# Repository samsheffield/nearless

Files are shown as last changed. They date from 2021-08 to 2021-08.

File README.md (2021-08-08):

# Nearless (Nearness 1U Rework)

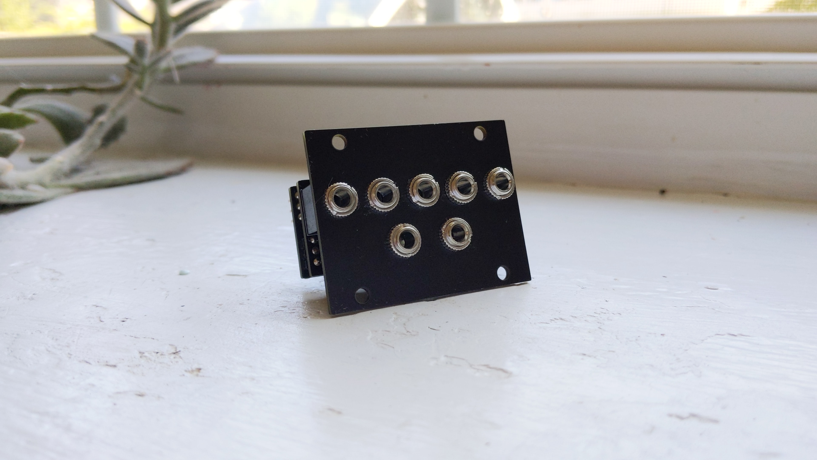
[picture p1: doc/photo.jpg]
Nearless


This is a small Intellijel 1U rework of Nearness designed by [*Jesper Särnesjö*](https://github.com/sarnesjo/nearness).

Minimal panning mixer for the Eurorack modular synthesizer system. Five inputs, two outputs. The closer an input is to either side, the greater its panning in that direction. 10hp.

Nearness is a product of the [*llllllll*](https://llllllll.co/t/prototyping-nearness-a-minimal-panning-mixer-module/8330) community.

## CHANGES

The module has been redesigned to fit an Intellijel 1U in 10hp, so there are two fewer inputs. Why 10hp? That's all I had free! :)

The resistor values have been simplified to accomodate the simple stereo spread. I tried to leave everything else as I found it.

## PCBS AND PANEL

The [kicad](kicad) directory contains the schematic and PCB and panel layouts as KiCad 5 projects.

Gerber files for fabrication are available in the [gerbers](gerbers) directory. 

Here is the [BOM](nearless_BOM.csv).

## IMPORTANT

1. I fabricated a working 0603 vesion of this module but decided to update the footprints to 0805 components before sharing (in kindness to others with bad vision). I have not built the 0805 version personally, but it should be fine. Thanks in advance to anyone willing to look over things/give it a try. Let me know how it goes.
2. On the bottom PCB the jumper pins and power header are on the backside, and the components and pin headers to connect boards are on the top. See [rear pic](doc/rear.jpg) to clarify.

## License

[CC BY-SA 4.0](http://creativecommons.org/licenses/by-sa/4.0/)

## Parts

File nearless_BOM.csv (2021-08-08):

Reference | Quantity | Value | Footprint
C1 C2 | 2 | 22p | 0805
C3 C4 | 2 | 22u | 0805
C5 C6 C7 C8 | 4 | 100n | 0805
D1 D2 | 2 | 1N5819HW | SOD-123
J1 J2 J3 J4 J5 J6 J7 | 7 |  | Thonkiconn Jack
P5 P6 P8 P10 | 4 |  | Header Pin 1x3
P9 P11 | 2 |  | Header Socket 1x3
P7 | 1 |  | Eurorack Power Header 2x5
R23 R24 | 2 | 1k | 0805
R1 R3 R5 R6 R8 R10 R15 R16 R17 R18 R19 R20 R21 R22 | 14 | 100k | 0805
R4 R7 | 2 | 300k | 0805
R2 R9 | 2 | 1M67 | 0805
U1 U2 | 2 | LME49720 | SOIC-8
 | 2 |  | Dual Shunt/Jumper

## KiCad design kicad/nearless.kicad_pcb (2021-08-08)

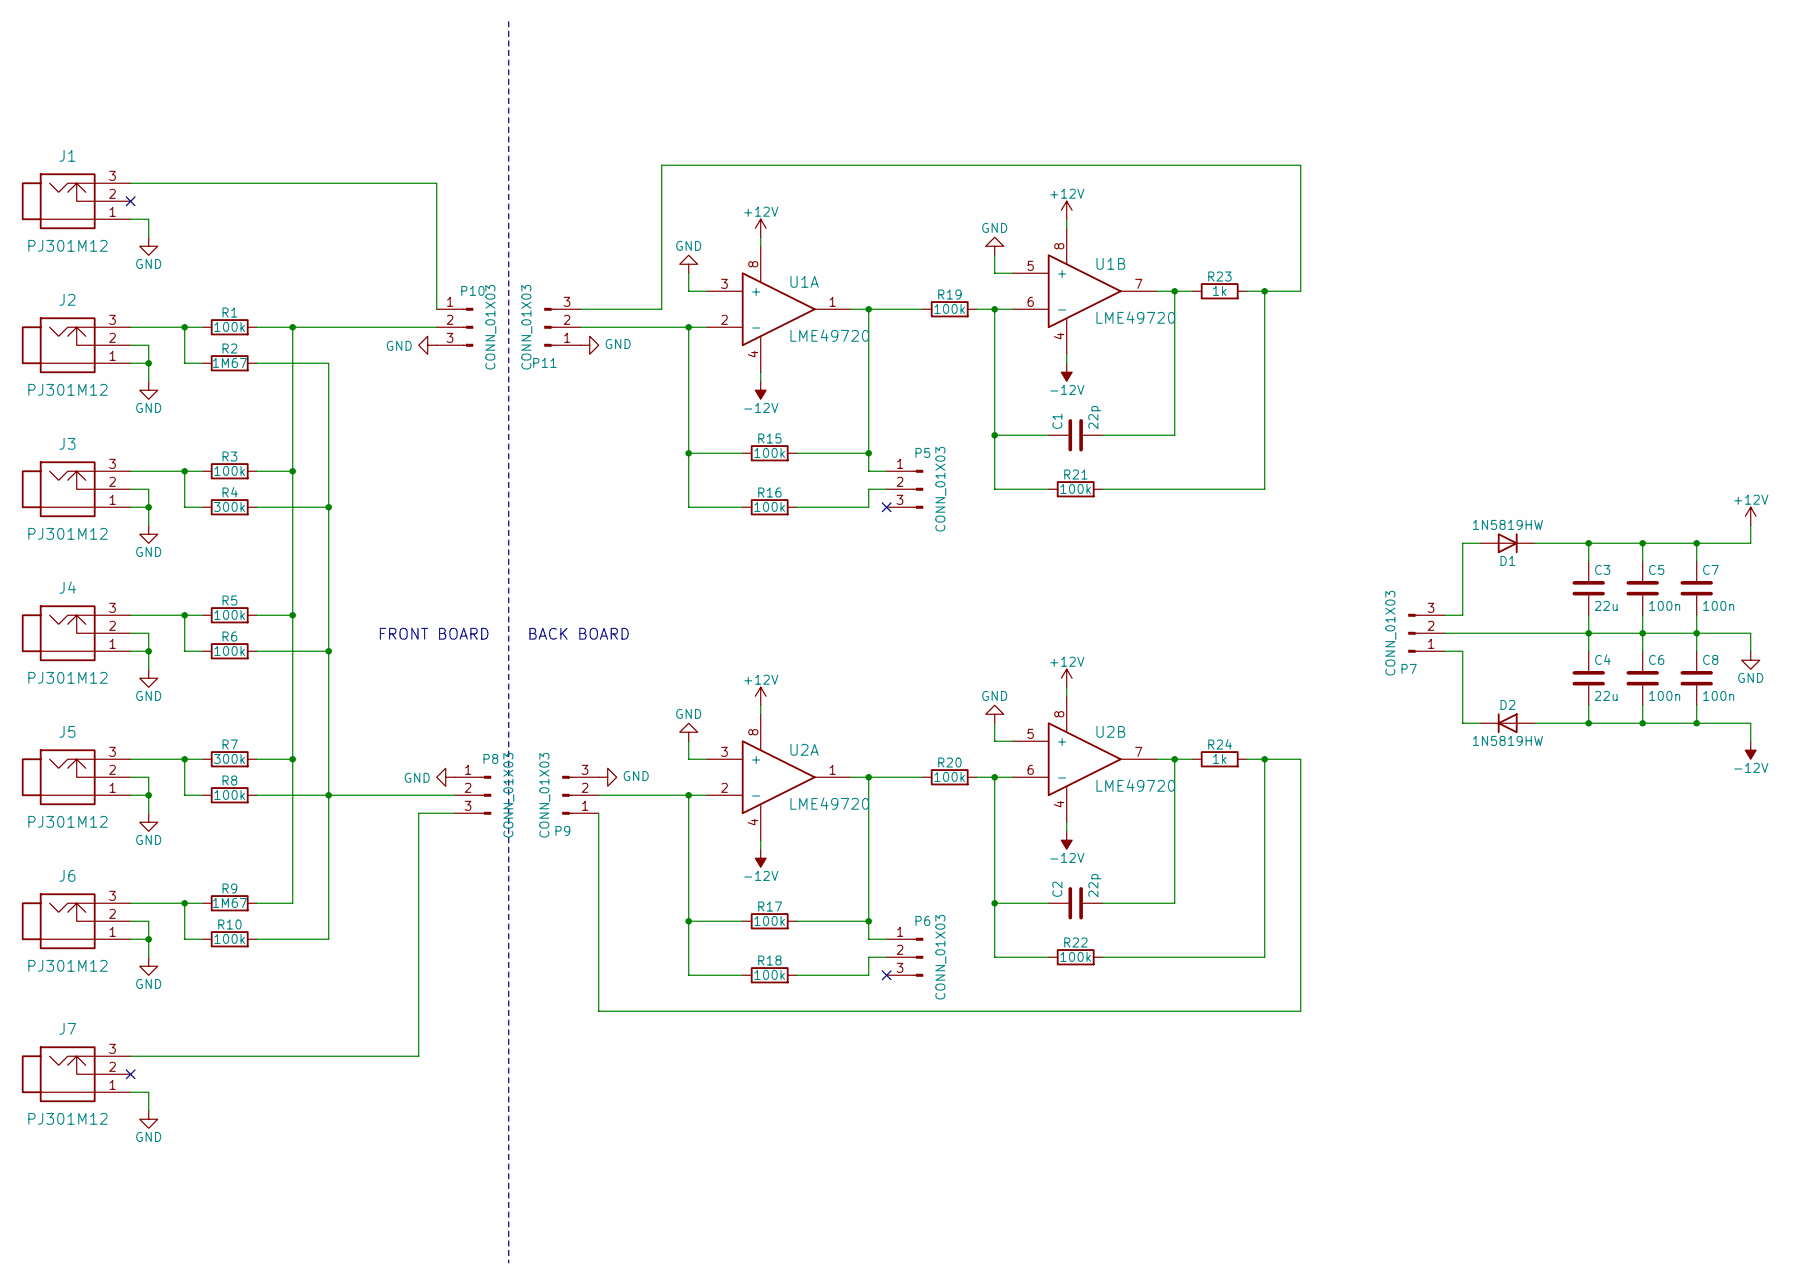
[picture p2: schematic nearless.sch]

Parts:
C1, C2: 22p; 0805
C3, C4: 22u; 0805
C5, C6, C7, C8: 100n; 0805
D1, D2: 1N5819HW; SOD-123
J1, J2, J3, J4, J5, J6, J7: PJ301M12
P5, P6, P8, P9, P10, P11: CONN_01X03; Pin_1x3
P7: CONN_01X03; Eurorack_2x5
R1, R3, R5, R6, R8, R10, R15, R16, R17, R18, R19, R20, R21, R22: 100k; 0805
R2, R9: 1M67; 0805
R4, R7: 300k; 0805
R23, R24: 1k; 0805
U1, U2: LME49720; SOIC-8

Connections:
+12V: C3.1, C5.1, C7.1, D1.1 (K), U1.8, U2.8
-12V: C4.2, C6.2, C8.2, D2.2 (A), U1.4, U2.4
GND: C3.2, C4.1, C5.2, C6.1, C7.2, C8.1, J1.1, J2.1, J2.2, J3.1, J3.2, J4.1, J4.2, J5.1, J5.2, J6.1, J6.2, J7.1, P7.2, P8.1, P9.3, P10.3, P11.1, U1.3 (+), U1.5 (+), U2.3 (+), U2.5 (+)
unnamed: C1.1, R19.2, R21.1, U1.6 (-)
unnamed: C1.2, R23.1, U1.7
unnamed: C2.1, R20.2, R22.1, U2.6 (-)
unnamed: C2.2, R24.1, U2.7
unnamed: D1.2 (A), P7.3
unnamed: D2.1 (K), P7.1
unnamed: J1.3, P10.1
unnamed: J2.3, R1.1, R2.1
unnamed: J3.3, R3.1, R4.1
unnamed: J4.3, R5.1, R6.1
unnamed: J5.3, R7.1, R8.1
unnamed: J6.3, R9.1, R10.1
unnamed: J7.3, P8.3
unnamed: P5.1, R15.2, R19.1, U1.1
unnamed: P5.2, R16.2
unnamed: P6.1, R17.2, R20.1, U2.1
unnamed: P6.2, R18.2
unnamed: P8.2, R2.2, R4.2, R6.2, R8.2, R10.2
unnamed: P9.1, R22.2, R24.2
unnamed: P9.2, R17.1, R18.1, U2.2 (-)
unnamed: P10.2, R1.2, R3.2, R5.2, R7.2, R9.2
unnamed: P11.2, R15.1, R16.1, U1.2 (-)
unnamed: P11.3, R21.2, R23.2

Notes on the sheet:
FRONT BOARD
BACK BOARD

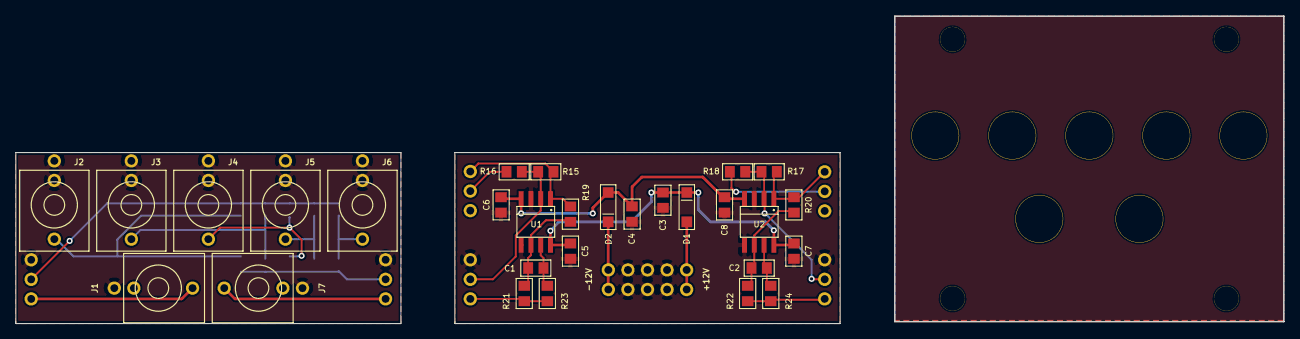
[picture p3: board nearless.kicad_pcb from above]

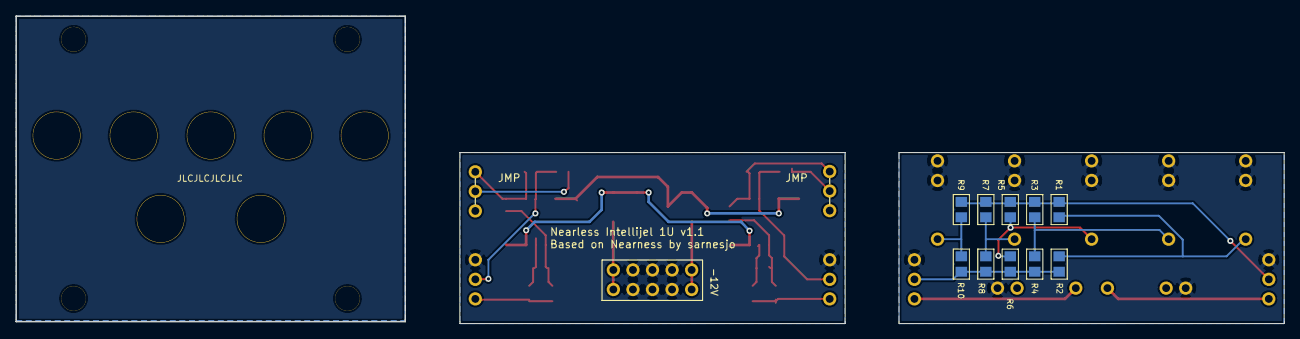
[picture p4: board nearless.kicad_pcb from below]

Board: 2 copper layers, 164.6 x 39.9 mm, 57 parts (10 on the bottom side), 26 nets.

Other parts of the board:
JACK: MonoJackHole; MountingHole_6.2mm
JACK#2, JACK#3, JACK#4, JACK#5, JACK#6, JACK#7: MonoJackHole; MountingHole_6.2mm
MNT: PanelMountingHole; MountingHole_3.2mm
MNT#2, MNT#3, MNT#4: PanelMountingHole; MountingHole_3.2mm
